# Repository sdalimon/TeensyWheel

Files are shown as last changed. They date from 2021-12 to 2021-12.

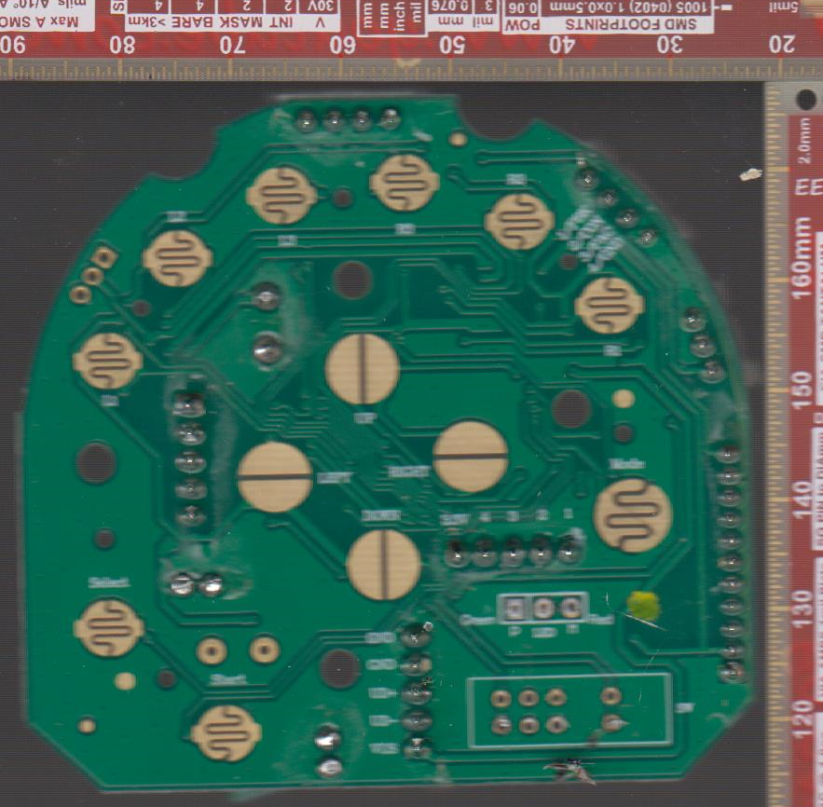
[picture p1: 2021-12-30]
Documentation/PCB_RevEng/PCB_cropped.png

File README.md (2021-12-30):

# TeensyWheel
A replacement PCB for the Flashfire ForceWheel WH2304-V gaming wheel

I bought the Flashfire ForceWheel WH2304-V because it was low cost, but found the button configuration annoying.  There are a lot of buttons, but many of them are shared with other functions (like the paddles and gearshift) leaving few usable ones.  Some of this was configurable, but it had to be done each time the unit was plugged in.

I knew a Teensy can act as a joystick so looked into using one as a replacement controller.  It didn't turn out that hard.  Most of the time was spent measuring the button and mounting hole locations on the original PCB to be sure the replecement would fit.

A bit of code later and now all buttons are indiviually mapped to joystick inputs.  

It works well, but I haven't used it a lot since I am having trouble with the button mapping in American Truck Simulator. They all show up and work in the Windows control panel.  You can change the button mapping in the software (Look at the end of IO_Pins.h)

The software does not implement the vibration or USB host features.

Sorry there isn't a BOM, but most of the parts were scavanged off the original PCB or are generic surface mount parts.

When ordering PCBs make sure they are 1.2 mm thick.

Documenation - PDF schematics, Assembly drawings and some reverse engineering of the original PCB
Output - Gerbers
Software - The Arduino project for the software - using with Arduino and TeensyDuino
Libraries - The local KiCad libraries

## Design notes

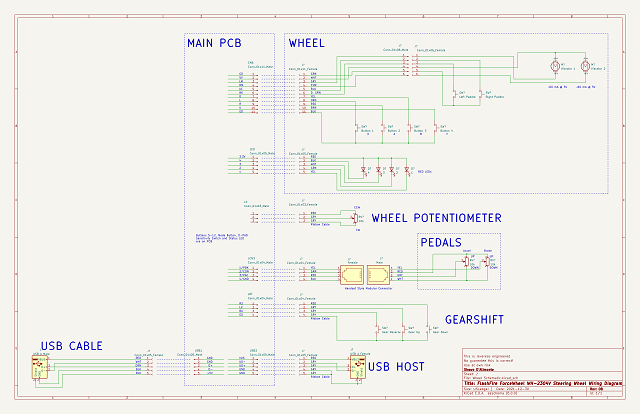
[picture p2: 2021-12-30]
Documentation/PCB_RevEng/Wheel_Schematic_small.png

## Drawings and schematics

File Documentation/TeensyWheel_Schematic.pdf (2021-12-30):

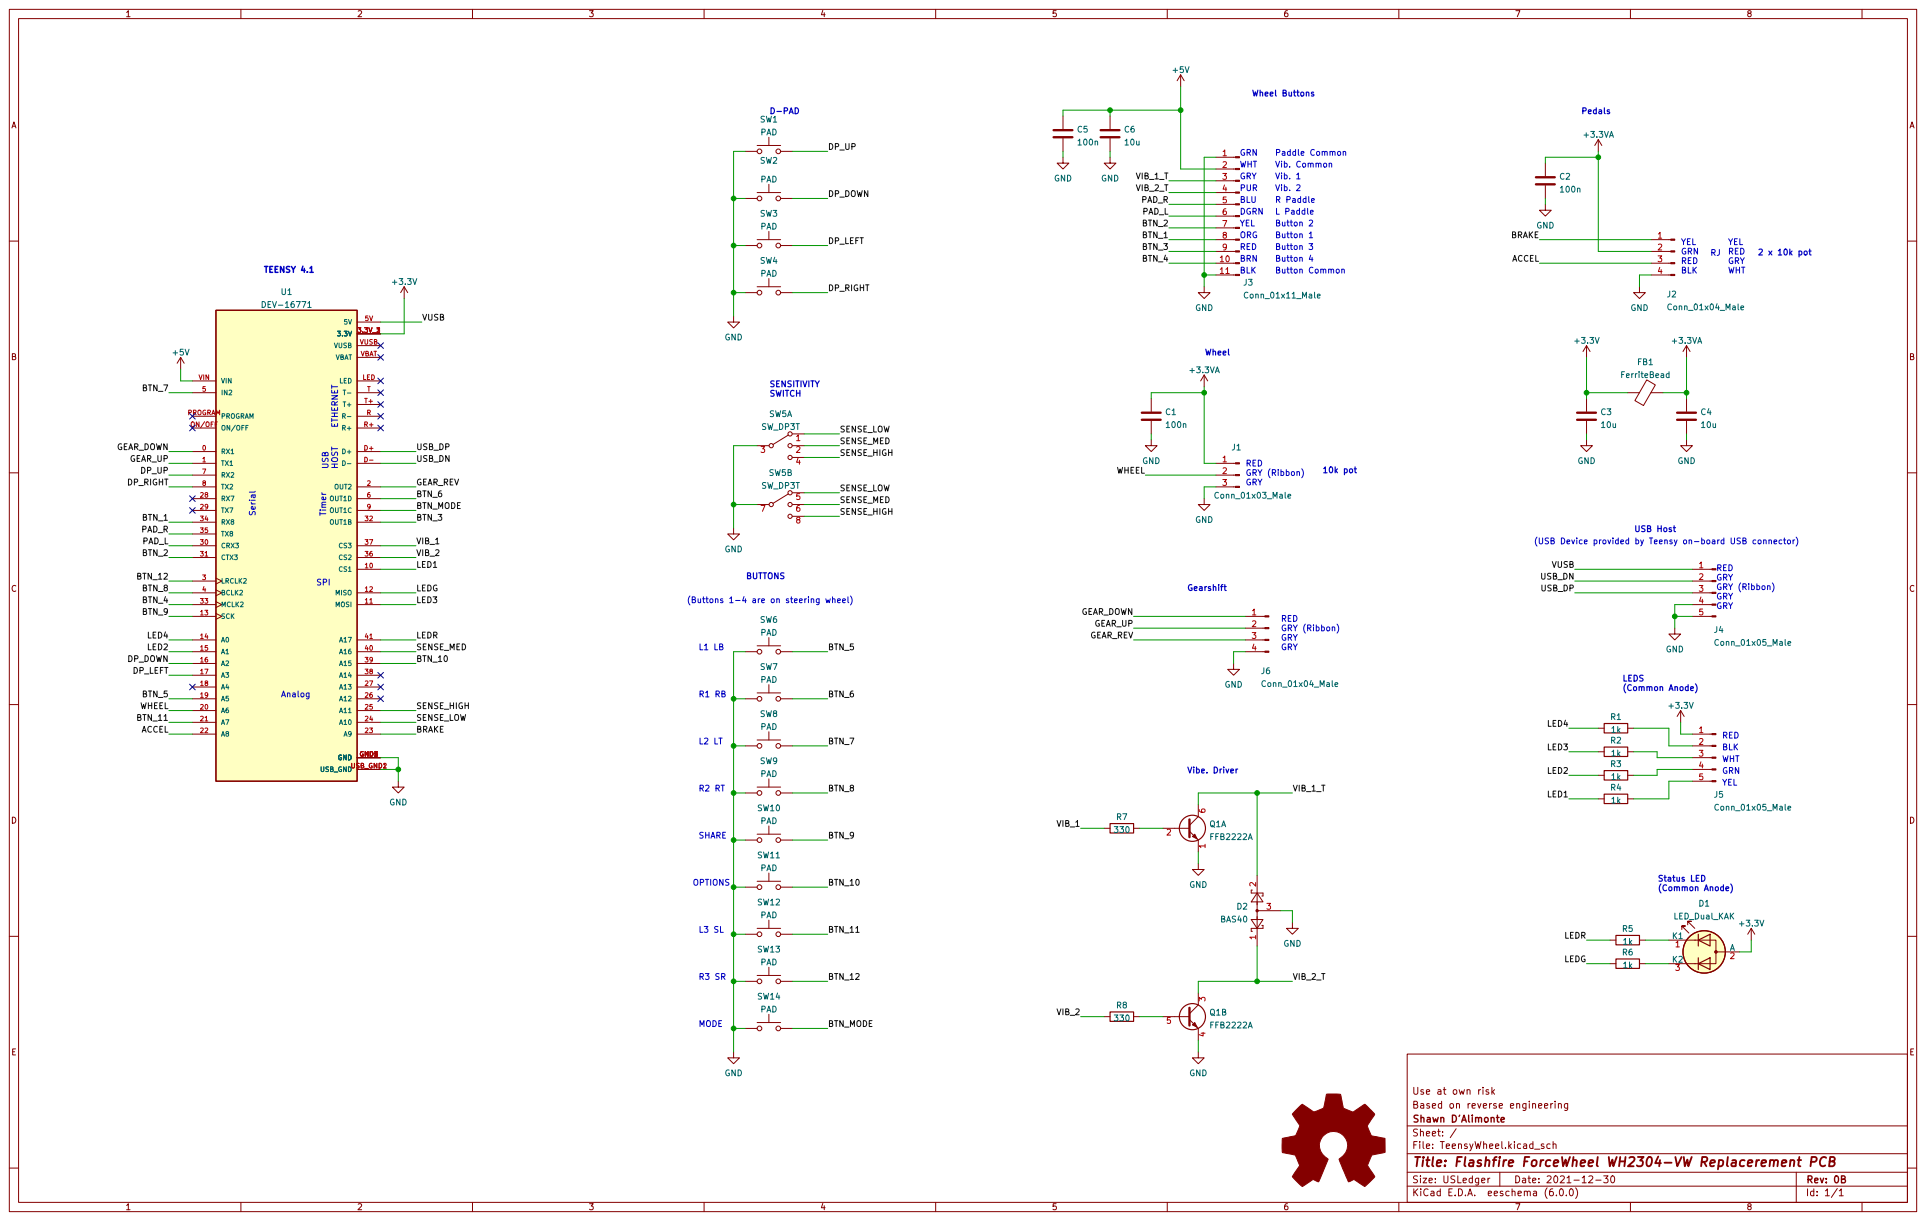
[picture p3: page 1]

L Paddle Vib. 2 Paddle Common R Paddle Vib. Common YEL RED ORG

Button 2 Button Common Button 3 Button 4 Button 1 WHT BLU GRN GRY

RED GRY (Ribbon) GRY GRY

YEL BLK WHT GRN

Id: 1/1 Title: Flashfire ForceWheel WH2304-VW Replacerement PCB

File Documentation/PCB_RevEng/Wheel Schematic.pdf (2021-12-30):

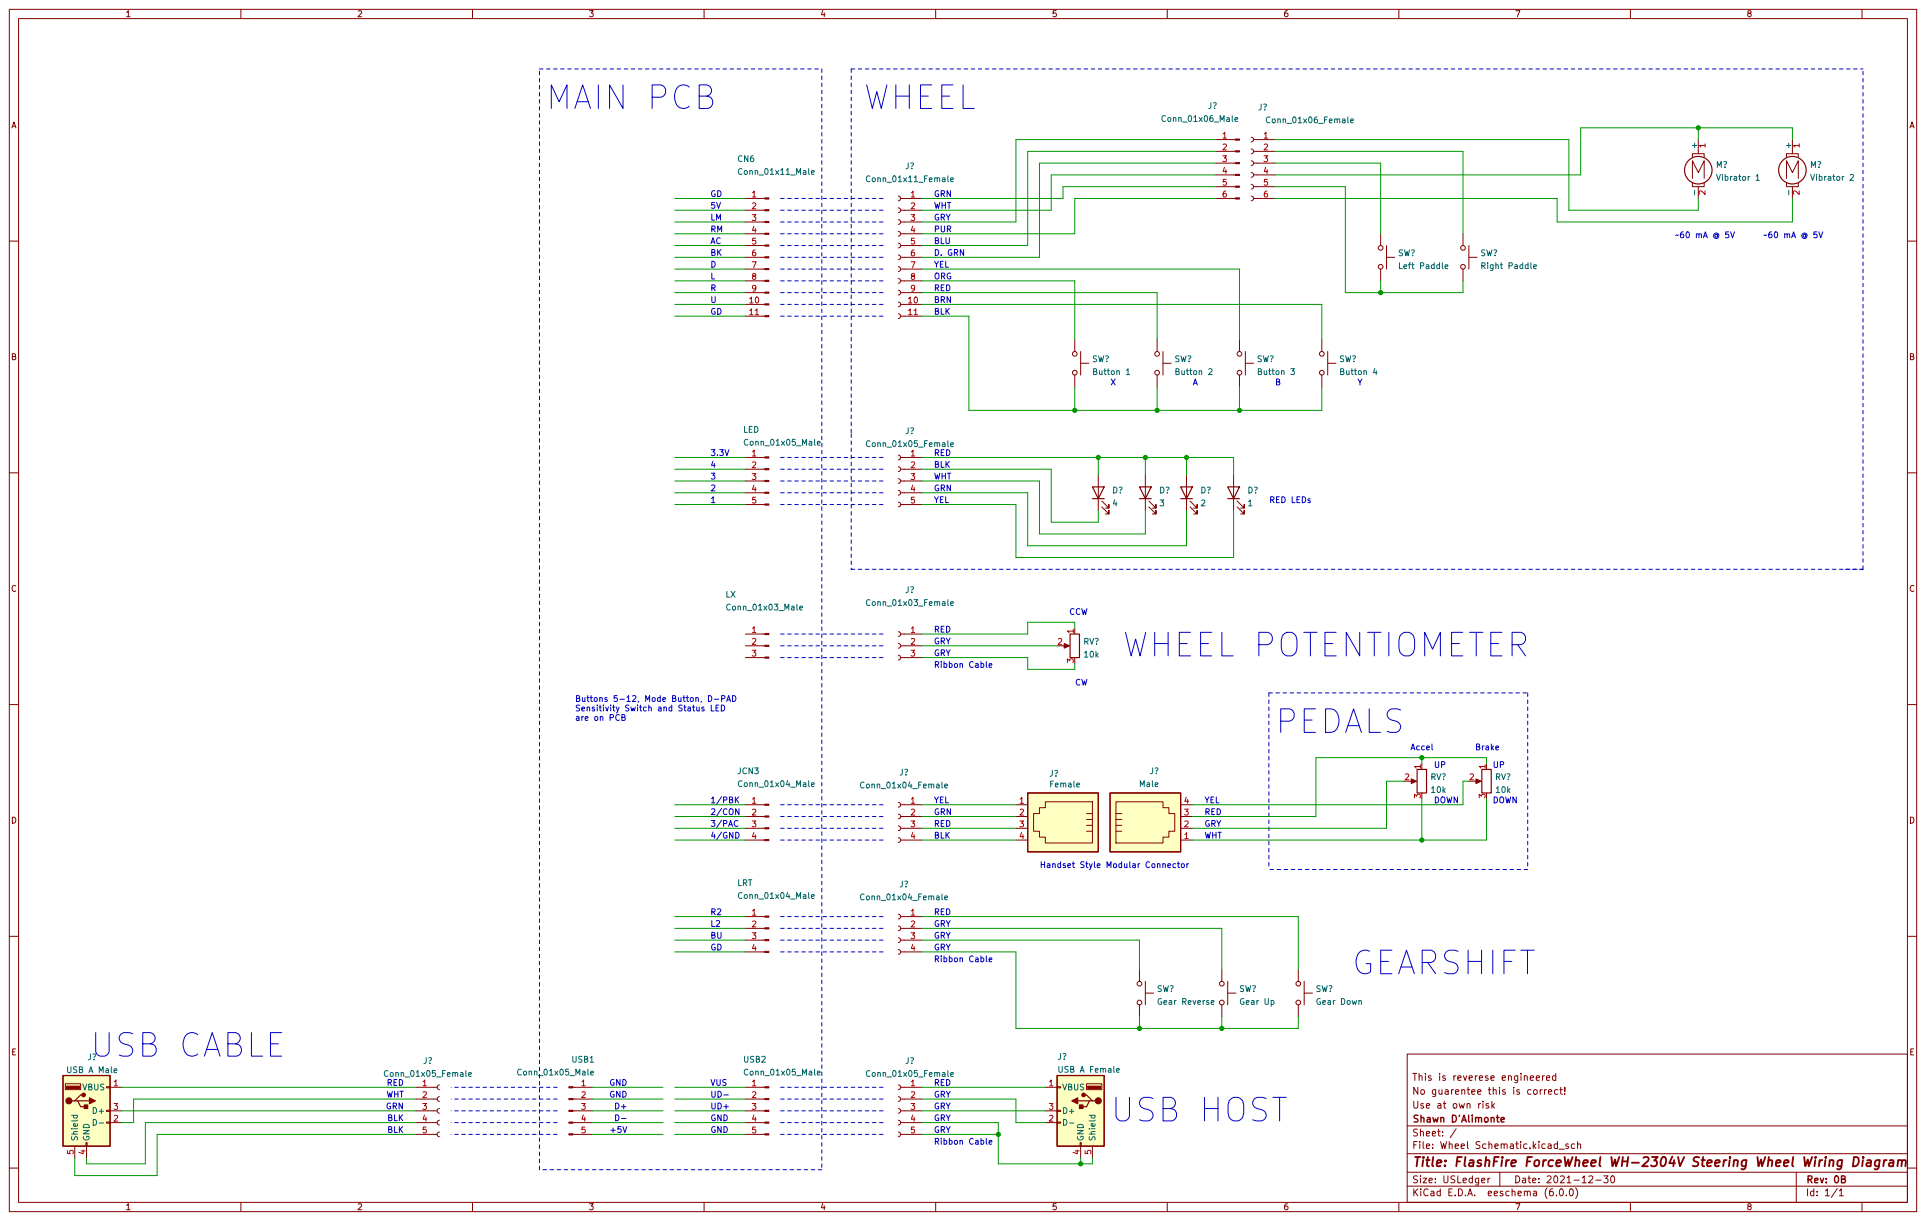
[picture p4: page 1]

Buttons 5-12, Mode Button, D-PAD

This is reverese engineered
File: Wheel Schematic.kicad_sch Sheet: / Shawn D'Alimonte Use at own risk No guarentee this is correct!

Id: 1/1 Title: FlashFire ForceWheel WH-2304V Steering Wheel Wiring Diagram

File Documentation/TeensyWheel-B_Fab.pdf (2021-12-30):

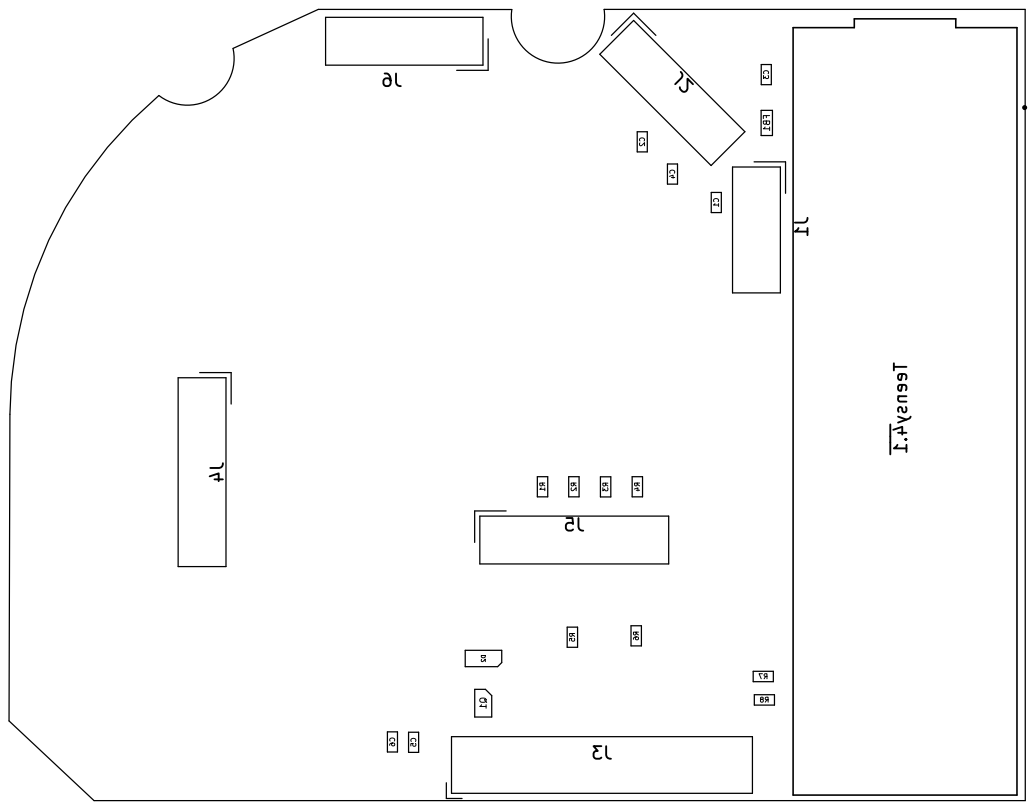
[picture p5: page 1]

Id: 1/1 Title: Flashfire ForceWheel WH2304-VW Replacerement PCB

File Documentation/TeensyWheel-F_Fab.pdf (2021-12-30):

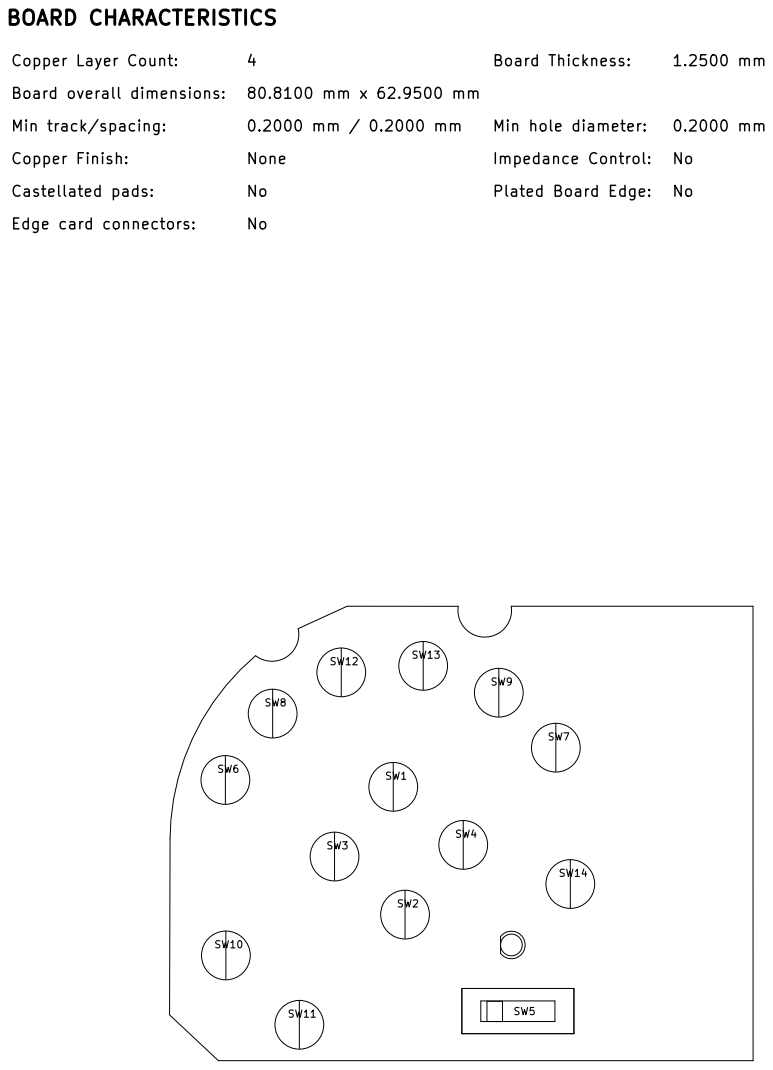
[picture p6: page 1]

Plated Board Edge: Min hole diameter: Board Thickness: NoNoNone

File: TeensyWheel.kicad_pcb Sheet: Shawn D'Alimonte Based on reverse engineering Use at own risk

Id: 1/1 Title: Flashfire ForceWheel WH2304-VW Replacerement PCB

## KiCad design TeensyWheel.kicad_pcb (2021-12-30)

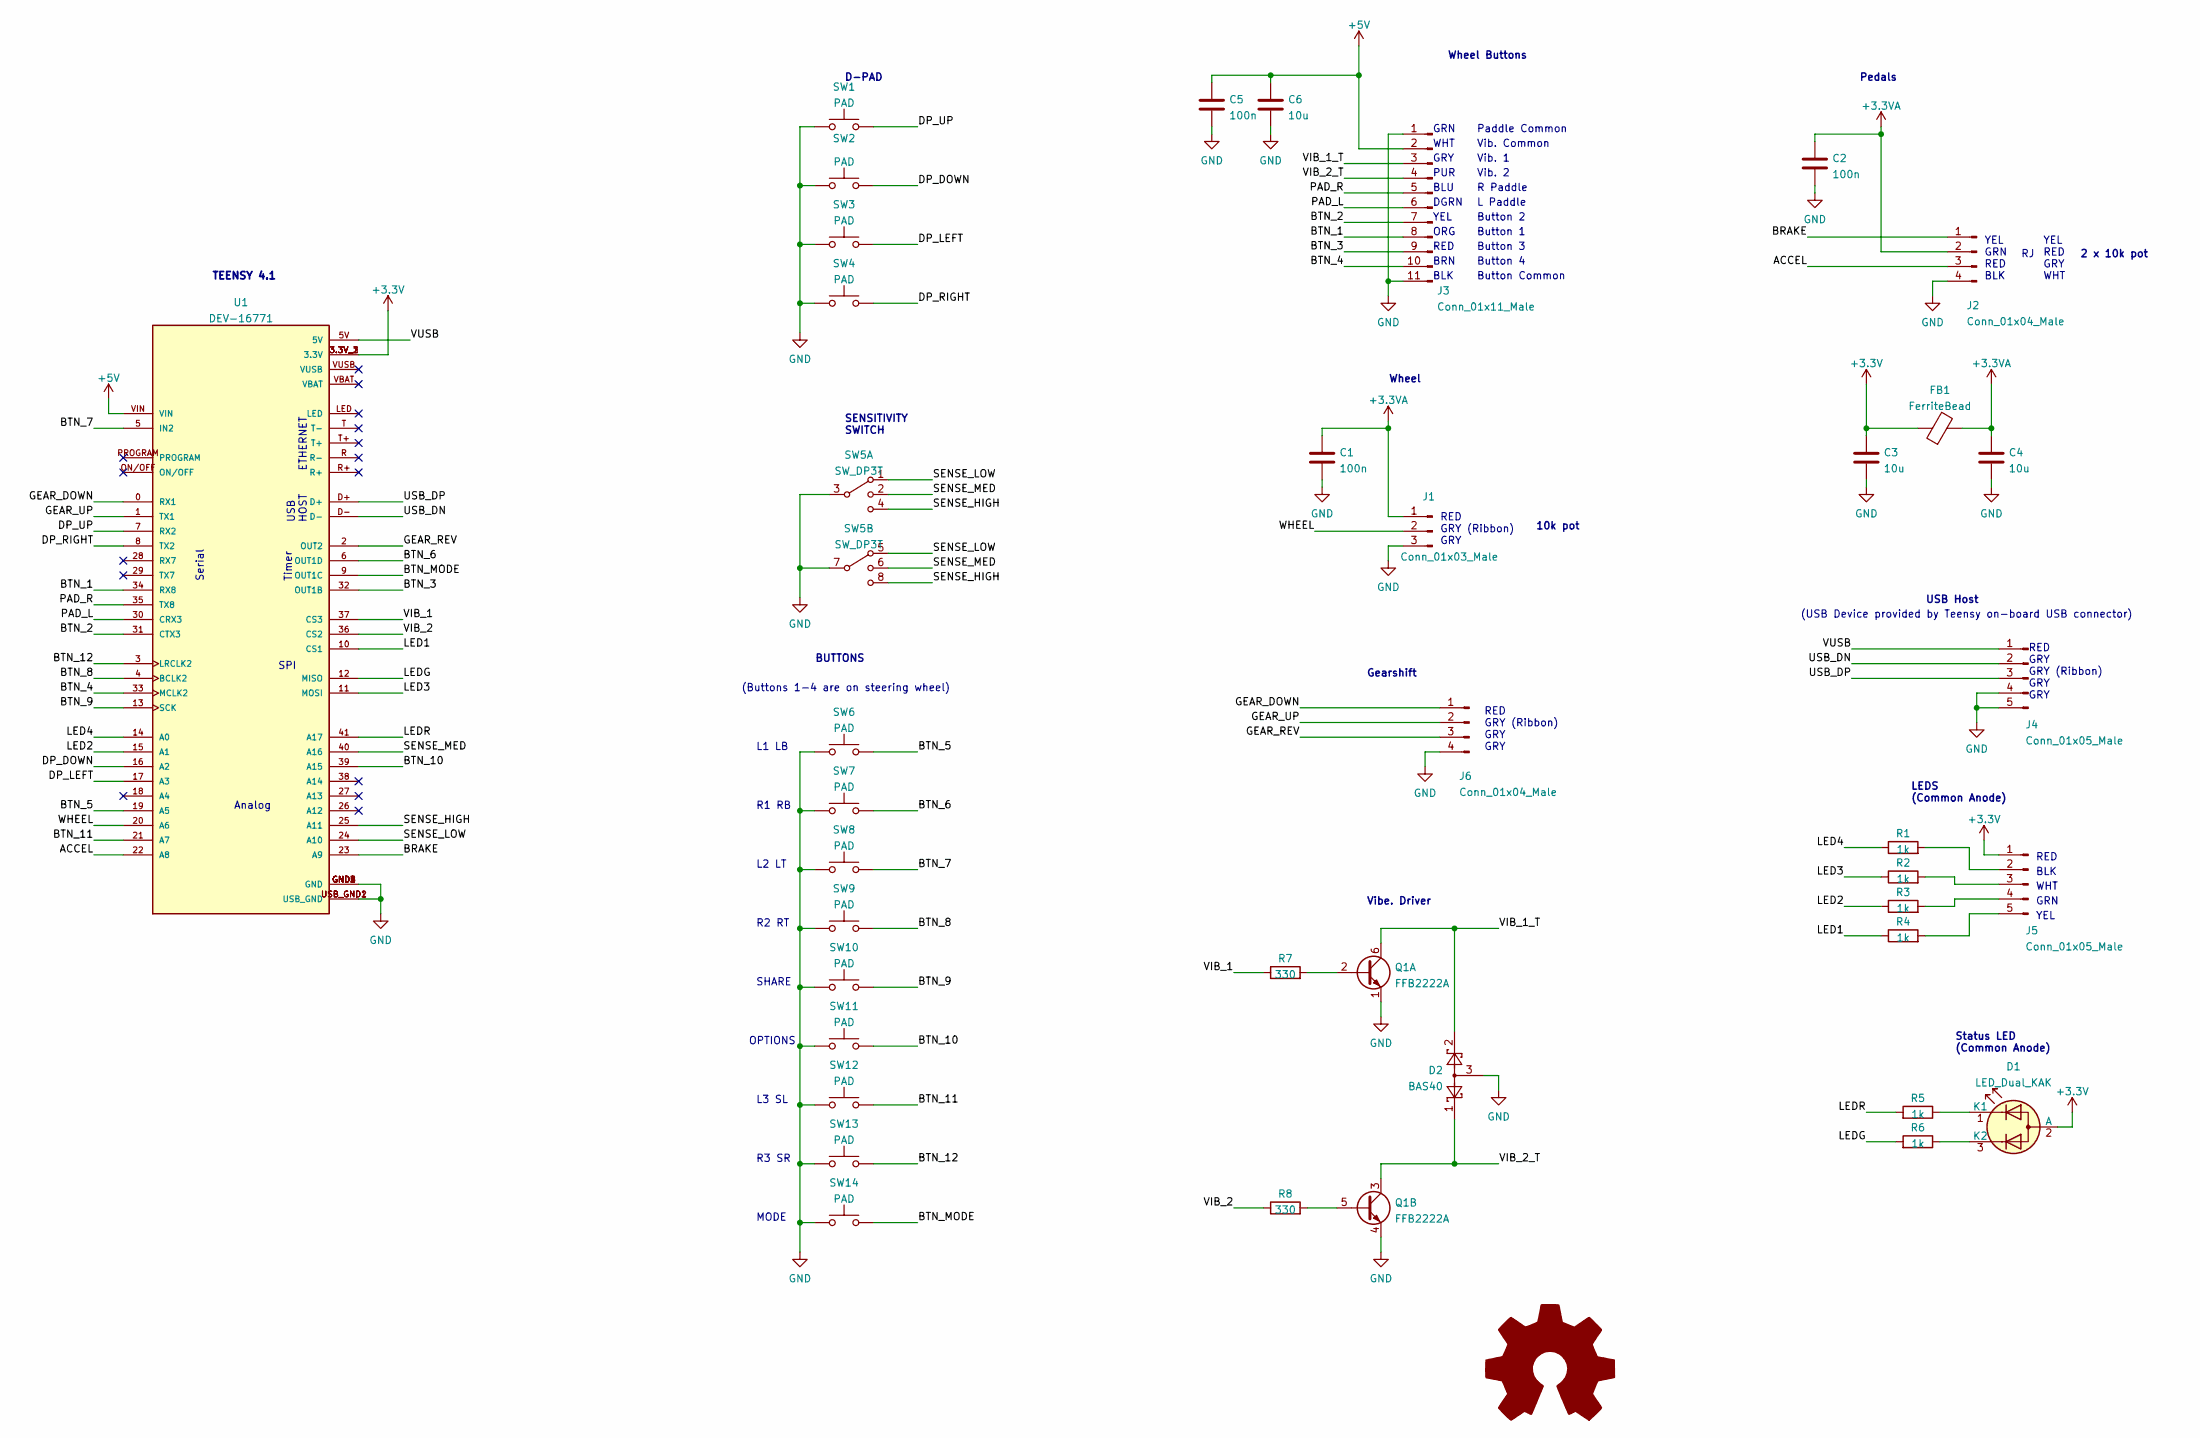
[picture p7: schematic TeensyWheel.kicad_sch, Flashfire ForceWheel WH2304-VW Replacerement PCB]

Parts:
C1, C2, C5: 100n; C_0603_1608Metric_Pad1.08x0.95mm_HandSolder
C3, C4, C6: 10u; C_0603_1608Metric_Pad1.08x0.95mm_HandSolder
D1: LED_Dual_KAK; LED_D3.0mm-3
D2: BAS40; SOT-23
FB1: FerriteBead; L_0805_2012Metric_Pad1.05x1.20mm_HandSolder
J1: Conn_01x03_Male; JST_EH_B3B-EH-A_1x03_P2.50mm_Vertical
J2, J6: Conn_01x04_Male; JST_EH_B4B-EH-A_1x04_P2.50mm_Vertical
J3: Conn_01x11_Male; JST_PH_B11B-PH-K_1x11_P2.00mm_Vertical
J4, J5: Conn_01x05_Male; JST_EH_B5B-EH-A_1x05_P2.50mm_Vertical
Q1: FFB2222A; SOT-363_SC-70-6
R1, R2, R3, R4, R5, R6: 1k; R_0603_1608Metric_Pad0.98x0.95mm_HandSolder
R7, R8: 330; R_0603_1608Metric_Pad0.98x0.95mm_HandSolder
SW1, SW2, SW3, SW4, SW6, SW7, SW8, SW9, SW10, SW11, SW12, SW13, SW14: PAD; Sw_PAD_6.5mm
SW5: SW_DP3T; Sense_Sw
U1: DEV-16771; MODULE_DEV-16771; PARTREV 4.1

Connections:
+3.3VA: C1.1, C2.1, C4.1, FB1.2, J1.1, J2.2
+3V3: C3.1, D1.2 (A), FB1.1, J5.1, U1.3.3V_1 (3.3V), U1.3.3V_2 (3.3V), U1.3.3V_3 (3.3V)
+5V: C5.1, C6.1, J3.2, U1.VIN
/ACCEL: J2.3, U1.22 (A8)
/BRAKE: J2.1, U1.23 (A9)
/BTN_1: J3.8, U1.34 (RX8)
/BTN_2: J3.9, U1.32 (OUT1B)
/BTN_3: J3.7, U1.31 (CTX3)
/BTN_4: J3.10, U1.33 (MCLK2)
/BTN_5: SW6.2, U1.19 (A5)
/BTN_6: SW7.2, U1.6 (OUT1D)
/BTN_7: SW8.2, U1.5 (IN2)
/BTN_8: SW9.2, U1.4 (BCLK2)
/BTN_9: SW10.2, U1.13 (SCK)
/BTN_10: SW11.2, U1.39 (A15)
/BTN_11: SW12.2, U1.21 (A7)
/BTN_12: SW13.2, U1.3 (LRCLK2)
/BTN_MODE: SW14.2, U1.9 (OUT1C)
/DP_DOWN: SW2.2, U1.16 (A2)
/DP_LEFT: SW3.2, U1.17 (A3)
/DP_RIGHT: SW4.2, U1.8 (TX2)
/DP_UP: SW1.2, U1.7 (RX2)
/GEAR_DOWN: J6.1, U1.0 (RX1)
/GEAR_REV: J6.3, U1.2 (OUT2)
/GEAR_UP: J6.2, U1.1 (TX1)
/LED1: R4.1, U1.10 (CS1)
/LED2: R3.1, U1.15 (A1)
/LED3: R2.1, U1.11 (MOSI)
/LED4: R1.1, U1.14 (A0)
/LEDG: R6.2, U1.12 (MISO)
/LEDR: R5.2, U1.41 (A17)
/PAD_L: J3.6, U1.30 (CRX3)
/PAD_R: J3.5, U1.35 (TX8)
/SENSE_HIGH: SW5.4, SW5.8, U1.25 (A11)
/SENSE_LOW: SW5.1, SW5.5, U1.24 (A10)
/SENSE_MED: SW5.2, SW5.6, U1.40 (A16)
/USB_DN: J4.2, U1.D-
/USB_DP: J4.3, U1.D+
/VIB_1: R7.1, U1.37 (CS3)
/VIB_1_T: D2.2, J3.3, Q1.6 (C1)
/VIB_2: R8.1, U1.36 (CS2)
/VIB_2_T: D2.1, J3.4, Q1.3 (C2)
/VUSB: J4.1, U1.5V
/WHEEL: J1.2, U1.20 (A6)
GND: C1.2, C2.2, C3.2, C4.2, C5.2, C6.2, D2.3, J1.3, J2.4, J3.1, J3.11, J4.4, J4.5, J6.4, Q1.1 (E1), Q1.4 (E2), SW1.1, SW2.1, SW3.1, SW4.1, SW5.3, SW5.7, SW6.1, SW7.1, SW8.1, SW9.1, SW10.1, SW11.1, SW12.1, SW13.1, SW14.1, U1.GND1 (GND), U1.GND2 (GND), U1.GND3 (GND), U1.GND4 (GND), U1.GND5 (GND), U1.USB_GND1 (USB_GND), U1.USB_GND2 (USB_GND)
unnamed: D1.1 (K1), R5.1
unnamed: D1.3 (K2), R6.1
unnamed: J5.2, R1.2
unnamed: J5.3, R2.2
unnamed: J5.4, R3.2
unnamed: J5.5, R4.2
unnamed: Q1.2 (B1), R7.2
unnamed: Q1.5 (B2), R8.2

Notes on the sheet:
Vib. 1
GRY
D-PAD
GRN
BLK
ETHERNET
ORG
RED
YEL
YEL GRN RED BLK
WHT
USB HOST
SHARE
Gearshift
Serial
R Paddle
L3 SL
Wheel
Button 1
Vibe. Driver
BRN
USB Host
(Buttons 1-4 are on steering wheel)
10k pot
PUR
Pedals
Button Common
SPI
L2 LT
L1 LB
2 x 10k pot
R3 SR
L Paddle
Button 2
Wheel Buttons
OPTIONS
Button 3
DGRN
MODE
R1 RB

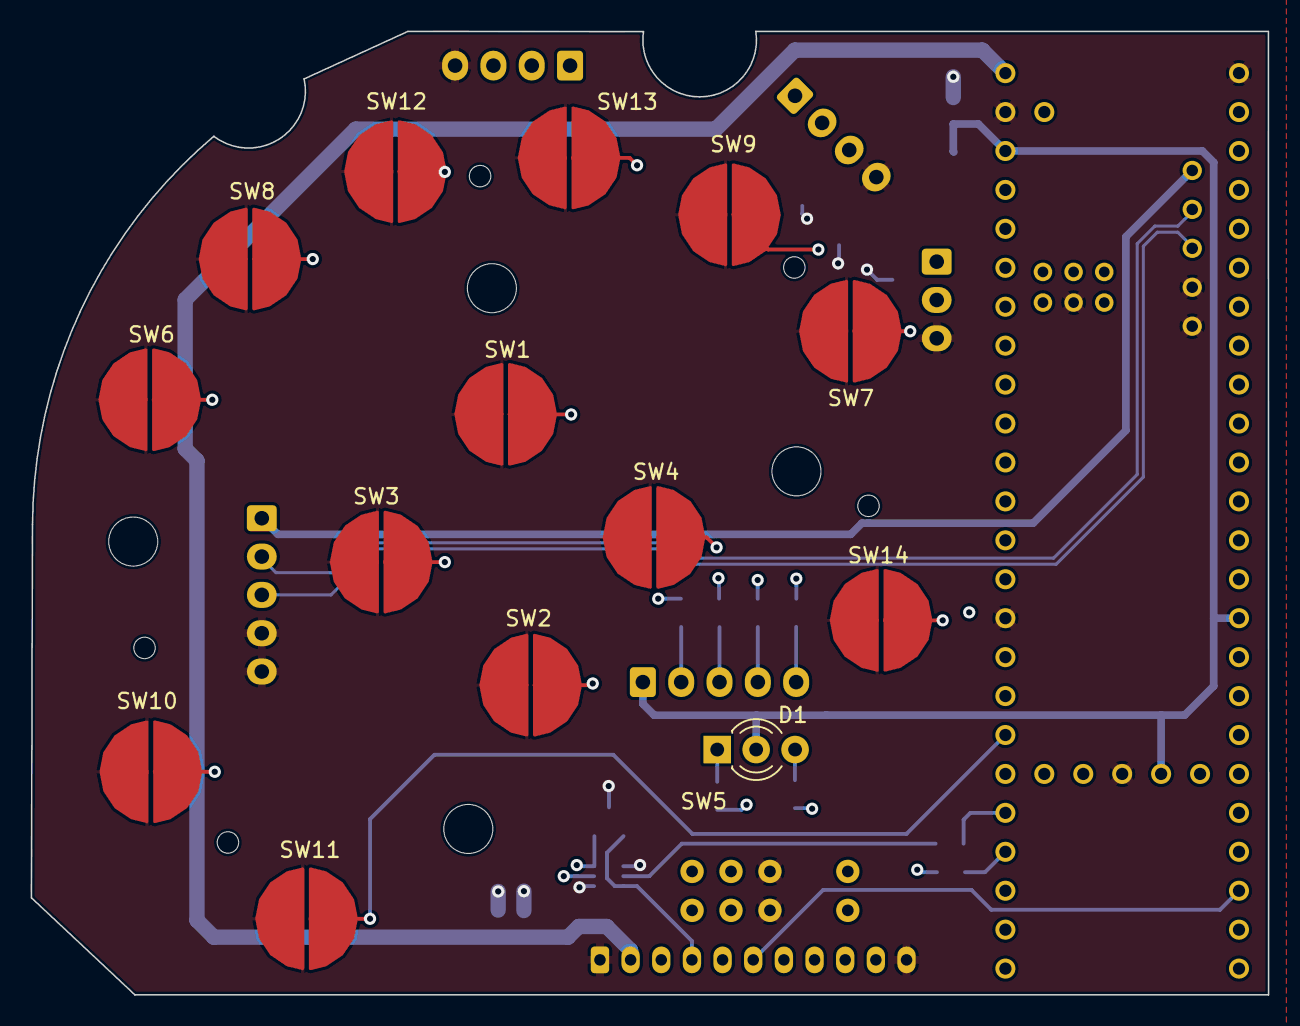
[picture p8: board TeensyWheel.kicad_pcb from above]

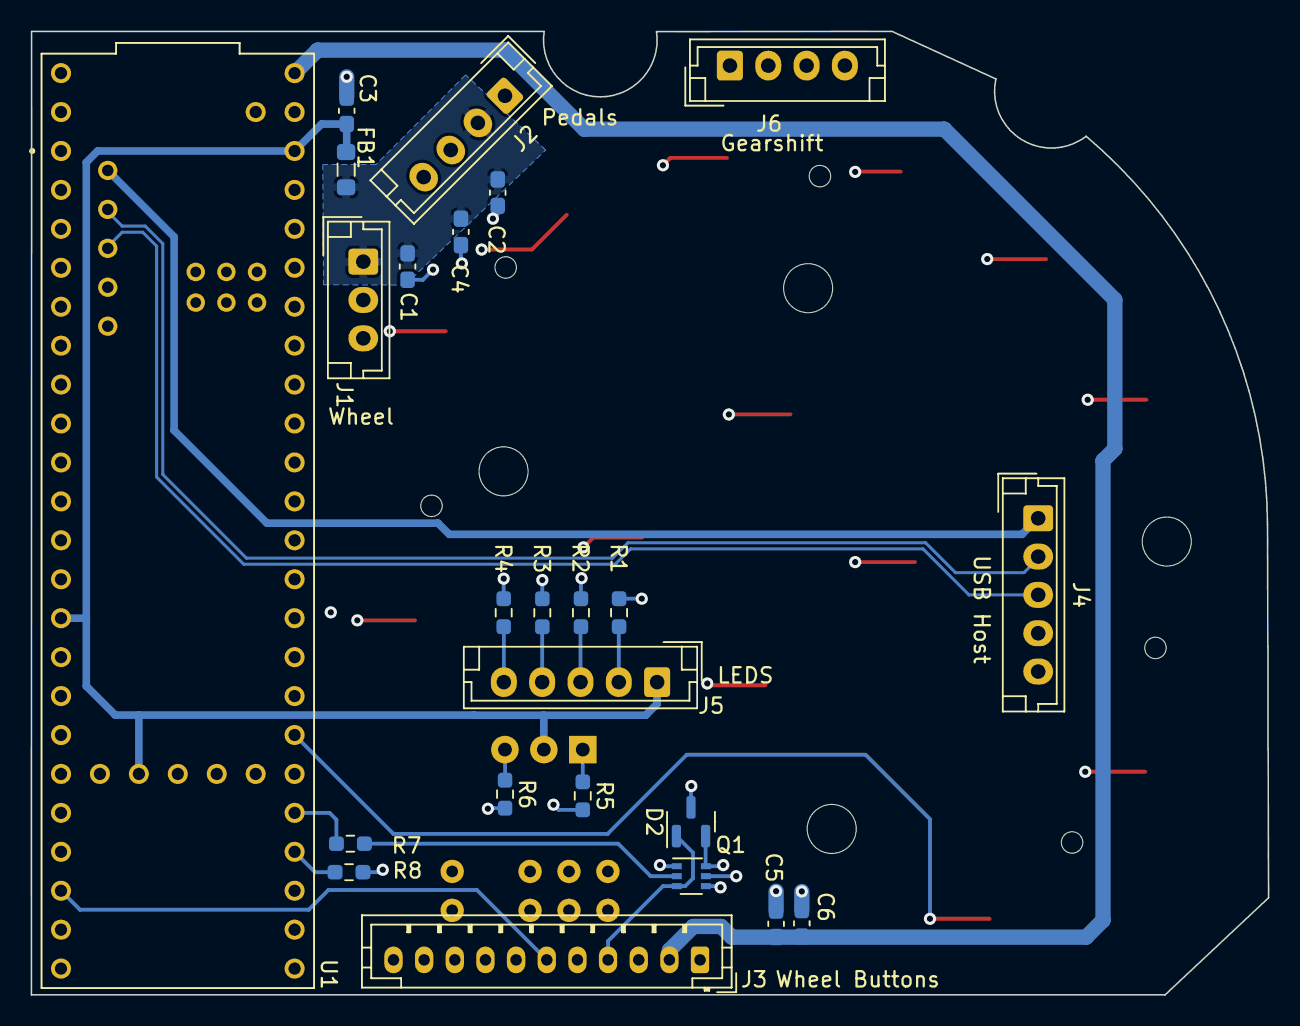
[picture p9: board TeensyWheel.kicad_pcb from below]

Board: 4 copper layers, 80.7 x 62.8 mm, 39 parts (24 on the bottom side), 53 nets.

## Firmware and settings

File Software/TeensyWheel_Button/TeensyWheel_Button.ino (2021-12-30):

/* Software for TeensyWheel - A replacement PCB for the Flashfire ForceWheel WH2304-V racing wheel
    using a Teensy 4.1
   You must select Joystick from the "Tools > USB Type" menu

   Shawn D'Alimonte 2021-12-30
*/

#include <Bounce2.h>
#include "IO_Pins.h"
#include <stdio.h>

// Create Bounce objects for each button.  The Bounce object
// automatically deals with contact chatter or "bounce", and
// it makes detecting changes very simple.

// Normal buttons
Bounce buttons[NUM_BTNS] = {Bounce()};

// Paddles
Bounce paddleLeft = Bounce(PAD_L, 10);
Bounce paddleRight = Bounce(PAD_R, 10);

// D-Pad
Bounce dUp = Bounce(DP_UP, 10);
Bounce dDown = Bounce(DP_DOWN, 10);
Bounce dLeft = Bounce(DP_LEFT, 10);
Bounce dRight = Bounce(DP_RIGHT, 10);

void setup() {
  int i;

  //Serial.begin(115200);
  //while (!Serial); // Wait for USB Serial
  //Serial.println("TeensyWheel");

  // Configure Input Pins
  pinMode(BTN_1, INPUT_PULLUP);
  pinMode(BTN_2, INPUT_PULLUP);
  pinMode(BTN_3, INPUT_PULLUP);
  pinMode(BTN_4, INPUT_PULLUP);
  pinMode(BTN_5, INPUT_PULLUP);
  pinMode(BTN_6, INPUT_PULLUP);
  pinMode(BTN_7, INPUT_PULLUP);
  pinMode(BTN_8, INPUT_PULLUP);
  pinMode(BTN_9, INPUT_PULLUP);
  pinMode(BTN_10, INPUT_PULLUP);
  pinMode(BTN_11, INPUT_PULLUP);
  pinMode(BTN_12, INPUT_PULLUP);
  pinMode(BTN_MODE, INPUT_PULLUP);
  pinMode(SENSE_HIGH, INPUT_PULLUP);
  pinMode(SENSE_MED, INPUT_PULLUP);
  pinMode(SENSE_LOW, INPUT_PULLUP);
  pinMode(SENSE_LOW, INPUT_PULLUP);
  pinMode(PAD_L, INPUT_PULLUP);
  pinMode(PAD_R, INPUT_PULLUP);
  pinMode(DP_UP, INPUT_PULLUP);
  pinMode(DP_DOWN, INPUT_PULLUP);
  pinMode(DP_LEFT, INPUT_PULLUP);
  pinMode(DP_RIGHT, INPUT_PULLUP);
  pinMode(GEAR_UP, INPUT_PULLUP);
  pinMode(GEAR_DOWN, INPUT_PULLUP);
  pinMode(GEAR_REV, INPUT_PULLUP);

  // Configure Output pins
  pinMode(LED1, OUTPUT);
  pinMode(LED2, OUTPUT);
  pinMode(LED3, OUTPUT);
  pinMode(LED4, OUTPUT);
  pinMode(LEDR, OUTPUT);
  pinMode(LEDG, OUTPUT);
  pinMode(VIB_1, OUTPUT);
  pinMode(VIB_2, OUTPUT);

  // LEDs off
  digitalWrite(LED1, HIGH);
  digitalWrite(LED2, HIGH);
  digitalWrite(LED3, HIGH);
  digitalWrite(LED4, HIGH);
  digitalWrite(LEDR, HIGH);
  digitalWrite(LEDG, HIGH);

  // Vibrator Off
  digitalWrite(VIB_1, LOW);
  digitalWrite(VIB_2, LOW);

  // Inititialize Bounce objects for buttons
  for (i = 0; i < NUM_BTNS; i++) {
    buttons[i].attach(BTN_MAP[i]);
    buttons[i].interval(10);
  }

  // Set all buttons and axes to default
  for (i = 0; i < NUM_BTNS; i++) {
    Joystick.button(i, 0);
  }
  Joystick.hat(-1);
  Joystick.X(512);
  Joystick.Y(1023);
  Joystick.Z(0);
  Joystick.Zrotate(512);
}

void loop() {
  int i;
  static int dx = 0;  // DPad X position
  static int dy = 0;  // DPad Y position
  static bool d_chg = 1; // Has Dpad changed?

  static int last_wheel = -1;
  static int last_acce1 = -1;
  static int last_brake = -1;
  static int last_paddle = -1;

  // Update all Bounce statuses
  for (i = 0; i < NUM_BTNS; i++) {
    buttons[i].update();
  }
  paddleLeft.update();
  paddleRight.update();
  dUp.update();
  dDown.update();
  dLeft.update();
  dRight.update();

  // Send Button Changes
  for (i = 0; i < NUM_BTNS; i++) {
    if (buttons[i].fell()) Joystick.button(i + 1, 1);
    if (buttons[i].rose()) Joystick.button(i + 1, 0);
  }

  // Handle D-Pad as POV Hat
  if (dUp.fell()) {
    dy = 1;
    d_chg = 1;
  }
  if (dUp.rose()) {
    dy = 0;
    d_chg = 1;
  }
  if (dDown.fell()) {
    dy = -1;
    d_chg = 1;
  }
  if (dDown.rose()) {
    dy = 0;
    d_chg = 1;
  }
  if (dRight.fell()) {
    dx = 1;
    d_chg = 1;
  }
  if (dRight.rose()) {
    dx = 0;
    d_chg = 1;
  }
  if (dLeft.fell()) {
    dx = -1;
    d_chg = 1;
  }
  if (dLeft.rose()) {
    dx = 0;
    d_chg = 1;
  }
  if (d_chg == 1) {
    if (dy == 1 && dx == 0)       Joystick.hat(0);
    else if (dy == 1  && dx == 1) Joystick.hat(45);
    else if (dy == 0  && dx == 1) Joystick.hat(90);
    else if (dy == -1 && dx == 1) Joystick.hat(135);
    else if (dy == -1  && dx == 0) Joystick.hat(180);
    else if (dy == -1  && dx == -1) Joystick.hat(225);
    else if (dy == 0  && dx == -1) Joystick.hat(270);
    else if (dy == 1  && dx == -1) Joystick.hat(315);
    else Joystick.hat(-1);
    d_chg = 0;
  }

  // Wheel is X axis
  {
    int wheel = 1023 - analogRead(WHEEL);
    if (wheel != last_wheel) {
      Joystick.X(wheel);
      last_wheel = wheel;
    }
  }

  // Accel is Y axis
  {
    int accel = 1023 - analogRead(ACCEL);
    if (accel != last_acce1) {
      Joystick.Y(accel);
      last_acce1 = accel;
    }
  }

  // Brake is Z axis
  {
    int brake = analogRead(BRAKE);
    if (brake != last_brake) {
      Joystick.Z(brake);
      last_brake = brake;
    }
  }

  // Paddles are Z Rotation axis
  {
    static int paddle = 512;
    if (paddleLeft.fell()) {
      paddle = 0;
    }
    if (paddleLeft.rose()) {
      paddle = 512;
    }
    if (paddleRight.fell()) {
      paddle = 1023;
    }
    if (paddleRight.rose()) {
      paddle = 512;
    }
    if (paddle != last_paddle) {
      Joystick.Zrotate(paddle);
      last_paddle = paddle;
    }
  }

}

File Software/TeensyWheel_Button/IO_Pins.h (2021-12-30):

#ifndef IO_PINS_H
#define IO_PINS_H

// IO Assignments

// Analog Inputs
const int WHEEL      = A6; // Wheel
const int ACCEL      = A8; // Pedals
const int BRAKE      = A9; // Pedals

// Digital Inputs
const int DP_UP      =  7; // D Pad
const int DP_DOWN    = 16; // D Pad
const int DP_LEFT    = 17; // D Pad
const int DP_RIGHT   =  8; // D Padd
const int PAD_R      = 35; // Paddles
const int PAD_L      = 30; // Paddles
const int GEAR_UP    =  1; // Gearshift
const int GEAR_DOWN  =  0; // Gearshift
const int GEAR_REV   =  2; // Gearshift
const int BTN_1      = 34; // Wheel Buttons
const int BTN_2      = 31; // Wheel Buttons
const int BTN_3      = 32; // Wheel Buttons
const int BTN_4      = 33; // Wheel Buttons
const int BTN_5      = 19; // L1 LB Button
const int BTN_6      =  6; // R1 RB Button
const int BTN_7      =  5; // L2 LT Button
const int BTN_8      =  4; // R2 RT Button
const int BTN_9      = 13; // SHARE Button - Oops conflicts with LED.  I hope i still works.
const int BTN_10     = 39; // OPTIONS Button
const int BTN_11     = 21; // L3 SL Button
const int BTN_12     =  3; // R3 SR Button
const int BTN_MODE   =  9; // MODE Button
const int SENSE_HIGH = 25; // Sensitivity Switch
const int SENSE_MED  = 40; // Sensitivity Switch
const int SENSE_LOW  = 24; // Sensitivity Switch

// Digital Outputs
const int LED1       = 10; // Wheel LEDS
const int LED2       = 15; // Wheel LEDs
const int LED3       = 11; // Wheel LEDs
const int LED4       = 14; // Wheel LEDs
const int LEDR       = 41; // Bicolour status LED
const int LEDG       = 12; // Bicolour status LED
const int VIB_1      = 37; // Vibrator Control
const int VIB_2      = 36; // Vibrator Control

// Input to Windows Joystick button mapping {Button 0 Input, Button 1 Input, ...}
const int NUM_BTNS = 18;
const int BTN_MAP[NUM_BTNS] = {BTN_1, BTN_2, BTN_3, BTN_4, BTN_5, BTN_6, BTN_7, BTN_8, BTN_9, BTN_10, BTN_11, BTN_12, \
                               BTN_MODE, GEAR_UP, GEAR_DOWN, GEAR_REV, SENSE_HIGH, SENSE_LOW};
#endif
